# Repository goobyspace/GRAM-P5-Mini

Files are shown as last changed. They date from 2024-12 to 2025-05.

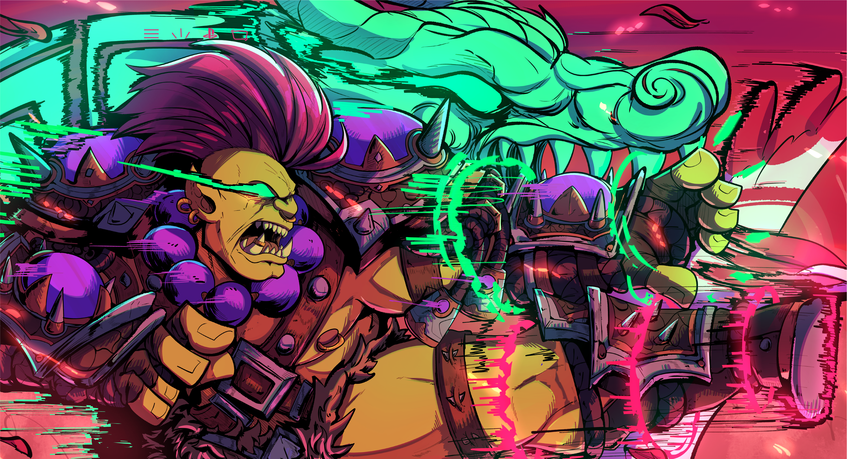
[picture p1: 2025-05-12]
GRAM FGC/v1.brook/art/Pashtrak Top Sticker.png

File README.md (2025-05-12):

# GRAM Slim

# Brook Version

This repo contains within the folder Gram FGC -> v1.brook, an edited version based on the v1.2 version that uses a brook P5-mini board. It's also edited specifically for a layout I find more comfortable, with the thumb button on the right hand outwards, instead of tucked under.

The PCB was made with heavy inspiration of the V1.2 PCB by [Quark](https://twitter.com/quark_works) as well as the (Flatbox)[https://github.com/jfedor2/flatbox], which includes an example of a Brook mini PCB & it's footprint in the rev3 version. Although the flatbox uses the PS3/PS4 mini, the pinout for the P5 mini has stayed the same.

This project was entirely for my own personal reasons, wanting the split thumb buttons & the pinky buttons on both sides moved down, as well as easier PS5 support (Hence the brook P5 mini). Don't expect the world from the PCB in here, it was my very first time learning Kicad, and if you want to take inspiration for your own edits, I heavily recommend this [stream](https://www.youtube.com/watch?v=zCp_-3P3b8c) by Quark. Though any keyboard PCB tutorials are a good start.

The gram top panel in the panels folder of V1.brook has also been edited to match the new button layout. The reason for choosing the V1.2 version was simply that it's the one I already owned, and I found it a lot easier to figure out what I was looking at with a dissected example next to me.

# Gram
For an ordering & assembly guide, check out the [GRAM-SLIM](https://github.com/GRAMCTRL/GRAM-SLIM) repo that this one was forked from!

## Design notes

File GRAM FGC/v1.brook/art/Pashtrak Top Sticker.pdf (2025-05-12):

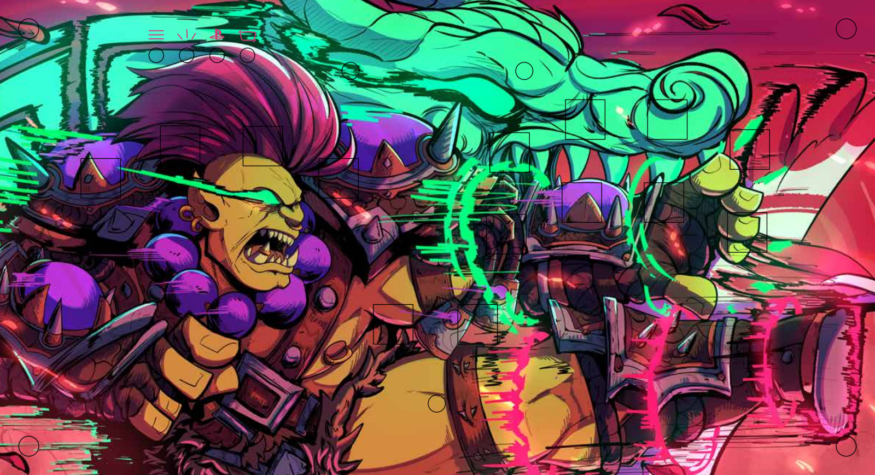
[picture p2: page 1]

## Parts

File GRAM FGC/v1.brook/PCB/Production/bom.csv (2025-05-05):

Designator | Footprint | Quantity | Value | LCSC Part #
A1 | Brook_PS3PS4_PCBA | 1 | Brook_PS3PS4_PCBA
R4, R5 | 0805 | 2 | 5.1k | C27834
S1, S10, S11, S12, S13, S14, S2, S3, S4, S5, S6, S7, S8, S9 | Kailh_socket_PG1350 | 14 | Keyswitch
SW1, SW2, SW3, SW4 | RT3301AF260Q | 4 | SW_Push
USB1 | HRO-TYPE-C-31-M-12 | 1 | HRO-TYPE-C-31-M-12 | C165948

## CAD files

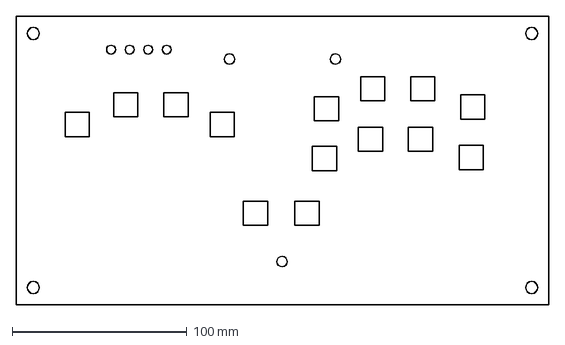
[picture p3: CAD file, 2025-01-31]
GRAM FGC/v1.brook/Panels/Gram Brook TOP.dxf
304.8 x 165.1 mm

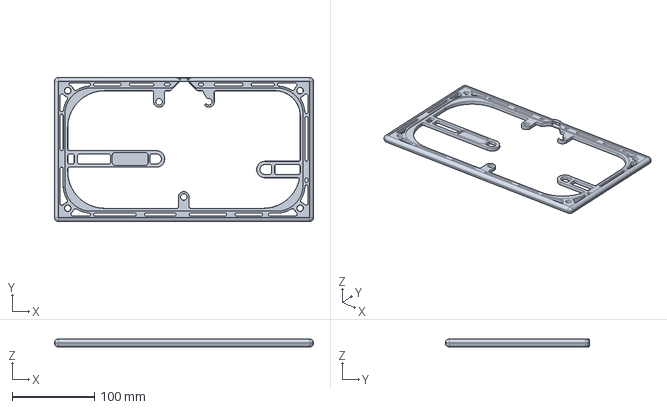
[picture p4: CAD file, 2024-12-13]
GRAM FGC/v1.brook/Plastics/universal frame.step
315.0 x 175.3 x 9.70 mm

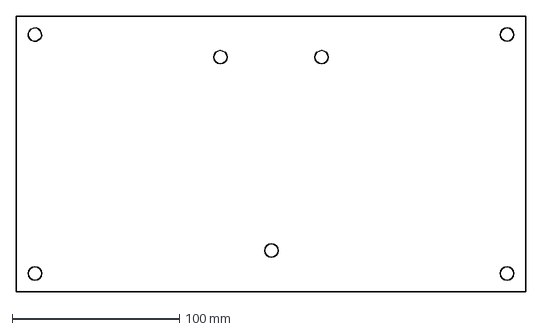
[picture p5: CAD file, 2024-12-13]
GRAM FGC/v1.brook/Panels/GRAM FGC BOTTOM TEMPLATE.dxf
304.8 x 165.1 mm

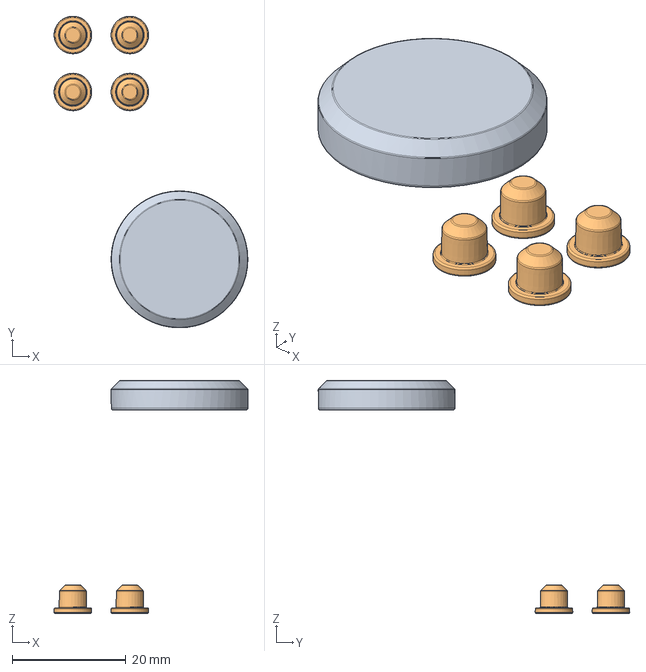
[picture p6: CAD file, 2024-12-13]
GRAM FGC/v1.brook/Plastics/30mm and menus.step
34.0 x 54.7 x 40.9 mm

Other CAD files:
GRAM FGC/v1.brook/Plastics/v2 buttons printable x10.stl

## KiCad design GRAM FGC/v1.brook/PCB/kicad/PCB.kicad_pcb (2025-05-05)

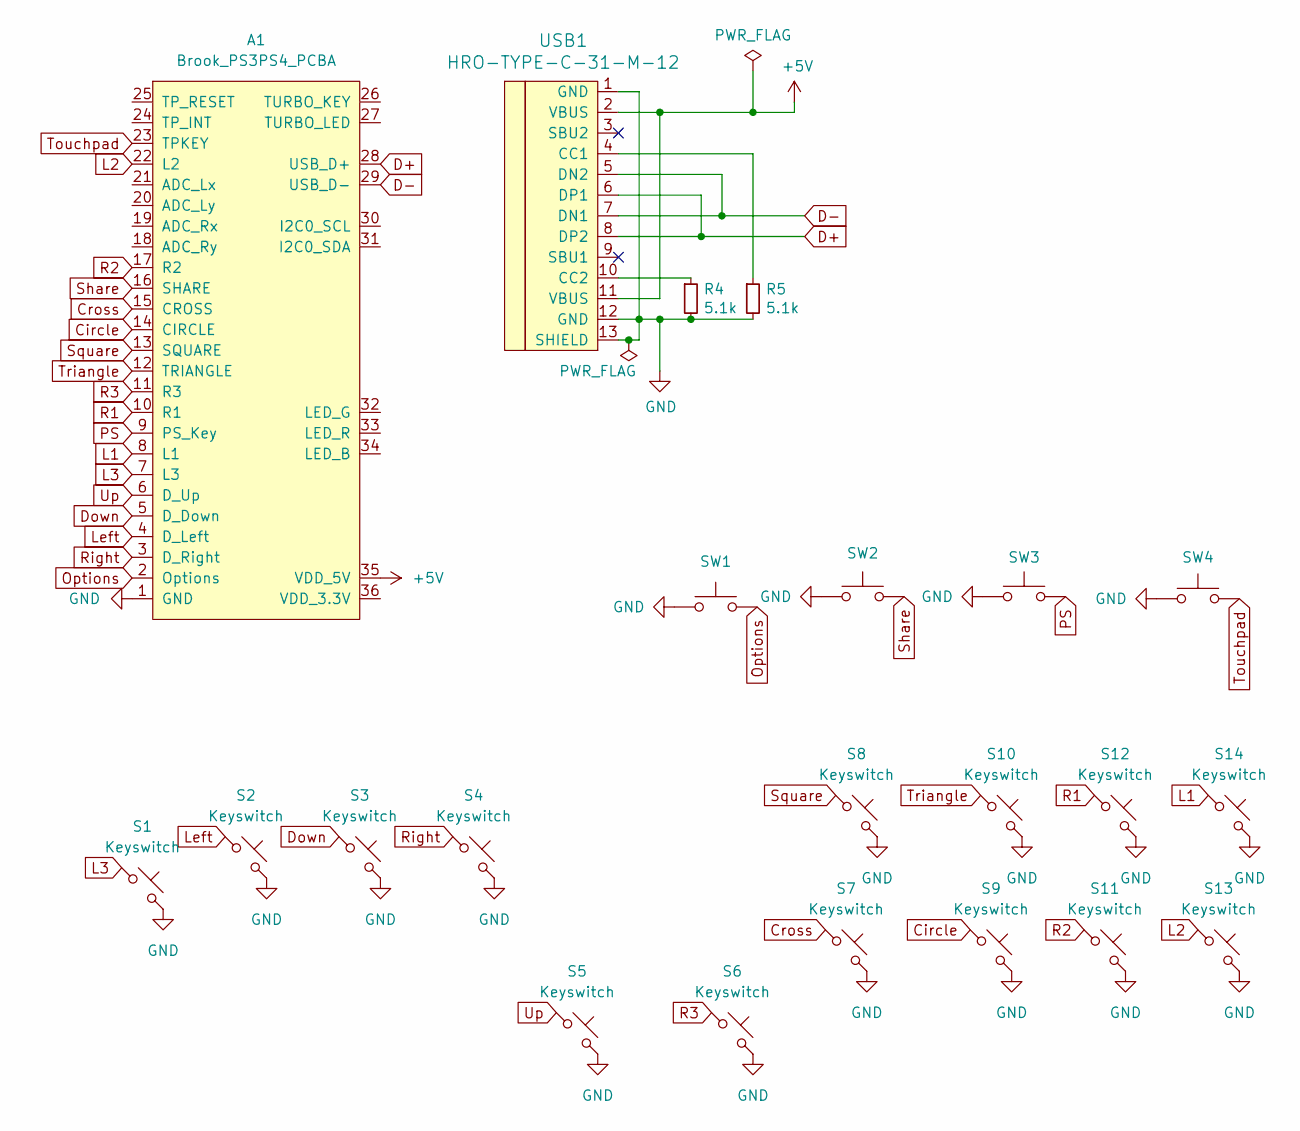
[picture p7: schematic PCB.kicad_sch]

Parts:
A1: Brook_PS3PS4_PCBA
R4, R5: 5.1k; R_0805_2012Metric; LCSC C27834
S1, S2, S3, S4, S5, S6, S7, S8, S9, S10, S11, S12, S13, S14: Keyswitch; Kailh_socket_PG1350
SW1, SW2, SW3, SW4: SW_Push; RT3301AF260Q
USB1: HRO-TYPE-C-31-M-12; LCSC C165948

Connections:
+5V: A1.35 (VDD_5V), USB1.2 (VBUS), USB1.11 (VBUS)
Circle: A1.14 (CIRCLE), S9.1
Cross: A1.15 (CROSS), S7.1
D+: A1.28 (USB_D+), USB1.6 (DP1), USB1.8 (DP2)
D-: A1.29 (USB_D-), USB1.5 (DN2), USB1.7 (DN1)
Down: A1.5 (D_Down), S3.1
GND: A1.1 (GND), R4.2, R5.2, S1.2, S2.2, S3.2, S4.2, S5.2, S6.2, S7.2, S8.2, S9.2, S10.2, S11.2, S12.2, S13.2, S14.2, SW1.1, SW2.1, SW3.1, SW4.1, USB1.1 (GND), USB1.12 (GND), USB1.13 (SHIELD)
L1: A1.8 (L1), S14.1
L2: A1.22 (L2), S13.1
L3: A1.7 (L3), S1.1
Left: A1.4 (D_Left), S2.1
unnamed: R5.1, USB1.4 (CC1)
unnamed: R4.1, USB1.10 (CC2)
Options: A1.2 (Options), SW1.2
PS: A1.9 (PS_Key), SW3.2
R1: A1.10 (R1), S12.1
R2: A1.17 (R2), S11.1
R3: A1.11 (R3), S6.1
Right: A1.3 (D_Right), S4.1
Share: A1.16 (SHARE), SW2.2
Square: A1.13 (SQUARE), S8.1
Touchpad: A1.23 (TPKEY), SW4.2
Triangle: A1.12 (TRIANGLE), S10.1
Up: A1.6 (D_Up), S5.1

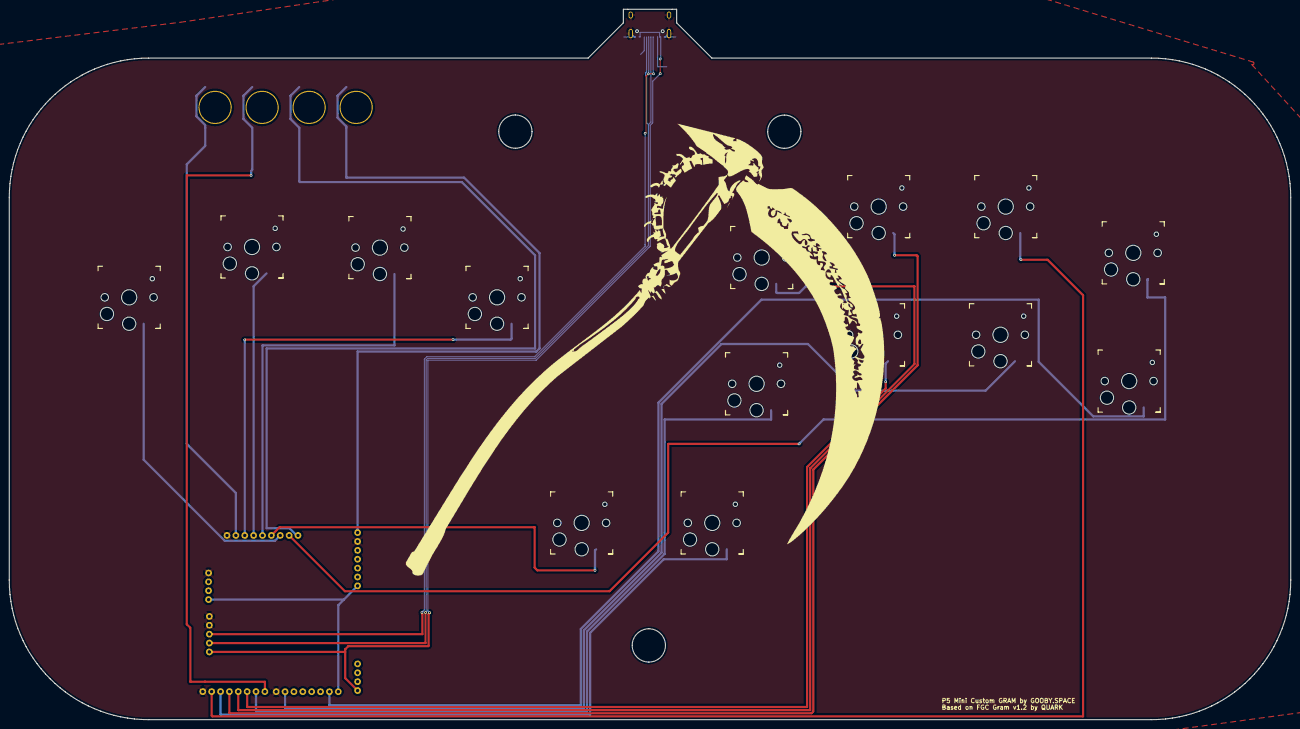
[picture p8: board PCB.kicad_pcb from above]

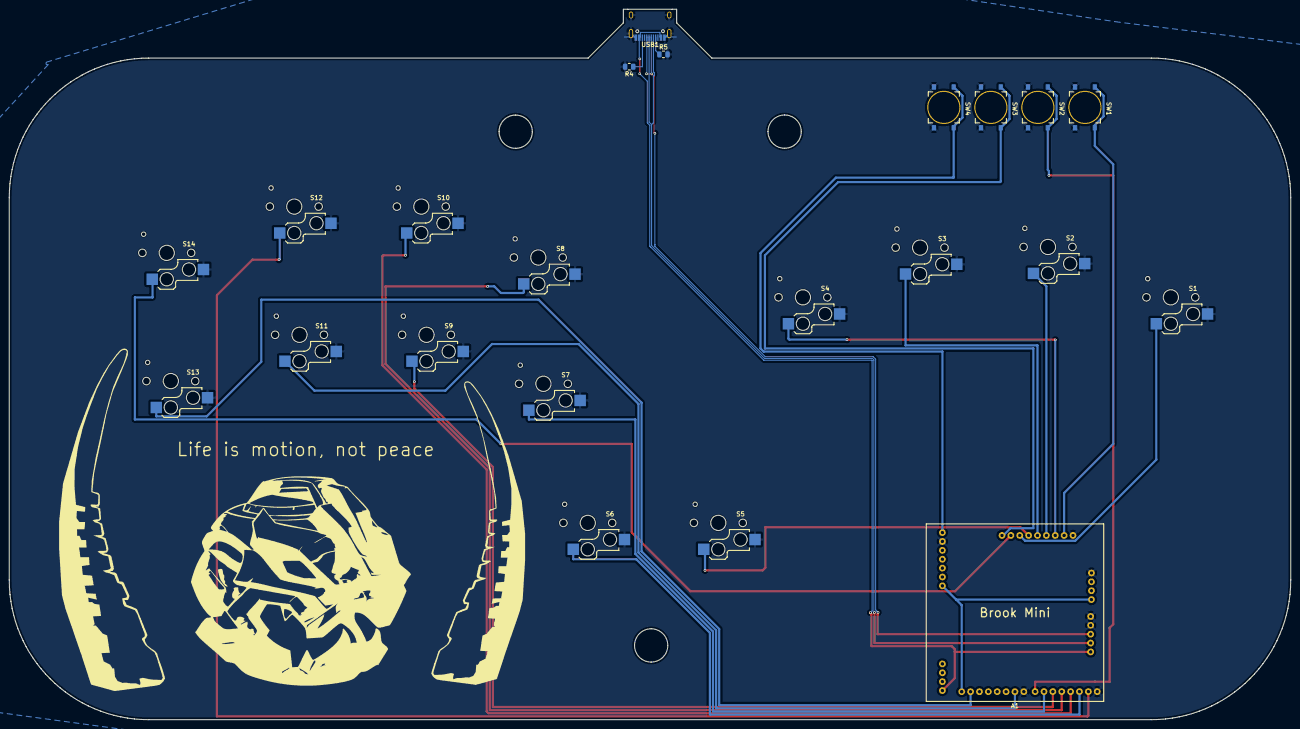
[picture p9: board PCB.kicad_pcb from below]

Board: 2 copper layers, 288.8 x 160.1 mm, 22 parts (4 on the bottom side), 24 nets.

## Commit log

2024-12-13 Updated with screwless and FGC
    [30mm and menus.step, Bottom Panel.step, Bottom panel template.dxf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]
2025-01-31 Add base files
    [30mm and menus.step, GRAM FGC BOTTOM TEMPLATE.dxf, GRAM FGC TOP TEMPLATE.dxf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]
2025-01-31 Fixed connections, top panel & gerbers
    [GRAM FGC TOP TEMPLATE.dxf, GRAM FGC TOP TEMPLATEa.dxf, Gram Brook TOP.dxf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]
2025-05-05 Added flatbox USB style
    [GRAM-HITBOX.kicad_sch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]
2025-05-12 Final working version
    [30mm and menus.step, Bottom Panel.step, Bottom panel template.dxf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]
